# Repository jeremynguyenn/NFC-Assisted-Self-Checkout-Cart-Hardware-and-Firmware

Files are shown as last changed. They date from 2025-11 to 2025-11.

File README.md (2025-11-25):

# Self-Checkout-Shopping-Cart
<p align="middle">
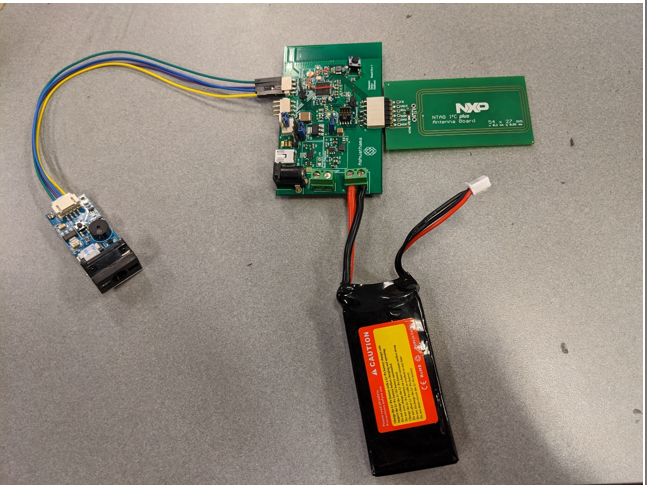
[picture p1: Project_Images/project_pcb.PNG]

</p>

This project was completed in the course Low Power Embedded Design Techniques at University of Colorado, Boulder under the guidance of Prof. Timothy Scherr and Prof. Randall Spalding during September 2019 - December 2019.  

## Hardware Components:
- Blue Gecko EFR32BG13 ([datasheet](https://www.silabs.com/documents/public/data-sheets/efr32bg13-datasheet.pdf))
- NXP NTAG NFC Module ([datasheet](https://www.nxp.com/docs/en/data-sheet/NT3H2111_2211.pdf))
- Barcode Scanner ([datasheet](https://www.waveshare.com/w/upload/3/3c/Barcode_Scanner_Module_User_Manual_EN.pdf))
- Lipo Lithium ion battery ([datasheet](https://cdn.sparkfun.com/datasheets/Prototyping/Lithium%20Ion%20Battery%20MSDS.pdf))
- Buck Converter - TPS560430XFDBVR ([datasheet](http://www.ti.com/general/docs/suppproductinfo.tsp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))
- LDO - LM117 ([datasheet](http://www.ti.com/lit/ds/symlink/lm1117.pdf))
- Battery Charging Management IC - MCP73213 ([datasheet](http://ww1.microchip.com/downloads/en/devicedoc/20002190c.pdf))
- Antenna
- Resistors
- Capacitors
- Inductors
- Adapter Jack
- Micro usb connector
- Debbugger

## Software Components:
- Simplicity Studio
- Android Application

## Features:
- The device connects to an Android app via Bluetooth, with NFC used to perform fast and secure pairing/authentication.

- A barcode module scans QR codes and barcodes to retrieve product details such as name and price through the Low Energy UART peripheral on the EFR32BG13.

- The scanned product information is transmitted to the Android application over BLE using the onboard antenna.

- The Android app displays the list of scanned items along with the total cost in the cart.

- The barcode scanner operates at 5V, while the NFC module requires 3.3V, provided through a buck converter and an LDO regulator respectively.

- The device is powered by a rechargeable battery, supported by an onboard battery-management circuit. A 12V adapter supplies stable power for charging the 7.4V battery.

- A debugger interface is included for flashing firmware and accessing debug print statements (VCOMM).

- Multiple test points and isolation points are placed on the PCB to assist during debugging.

- The board can also receive power from alternative sources through USB.

## Block Diagram:

### Hardware Block Diagram

<p align="middle">
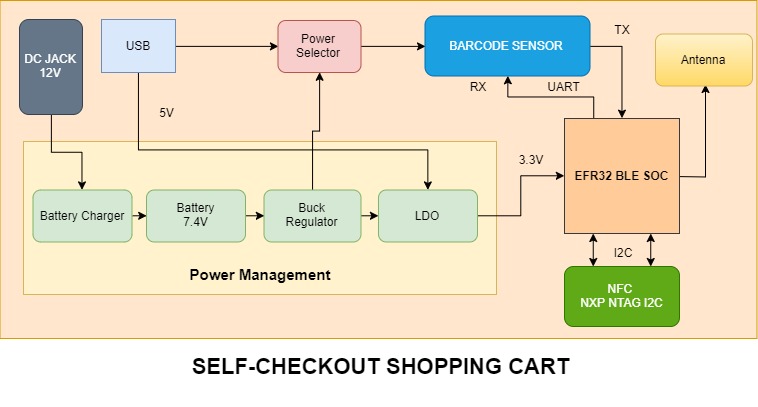
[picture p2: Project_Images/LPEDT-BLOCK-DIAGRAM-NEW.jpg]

</p>

### Software Block Diagram

<p align="middle">
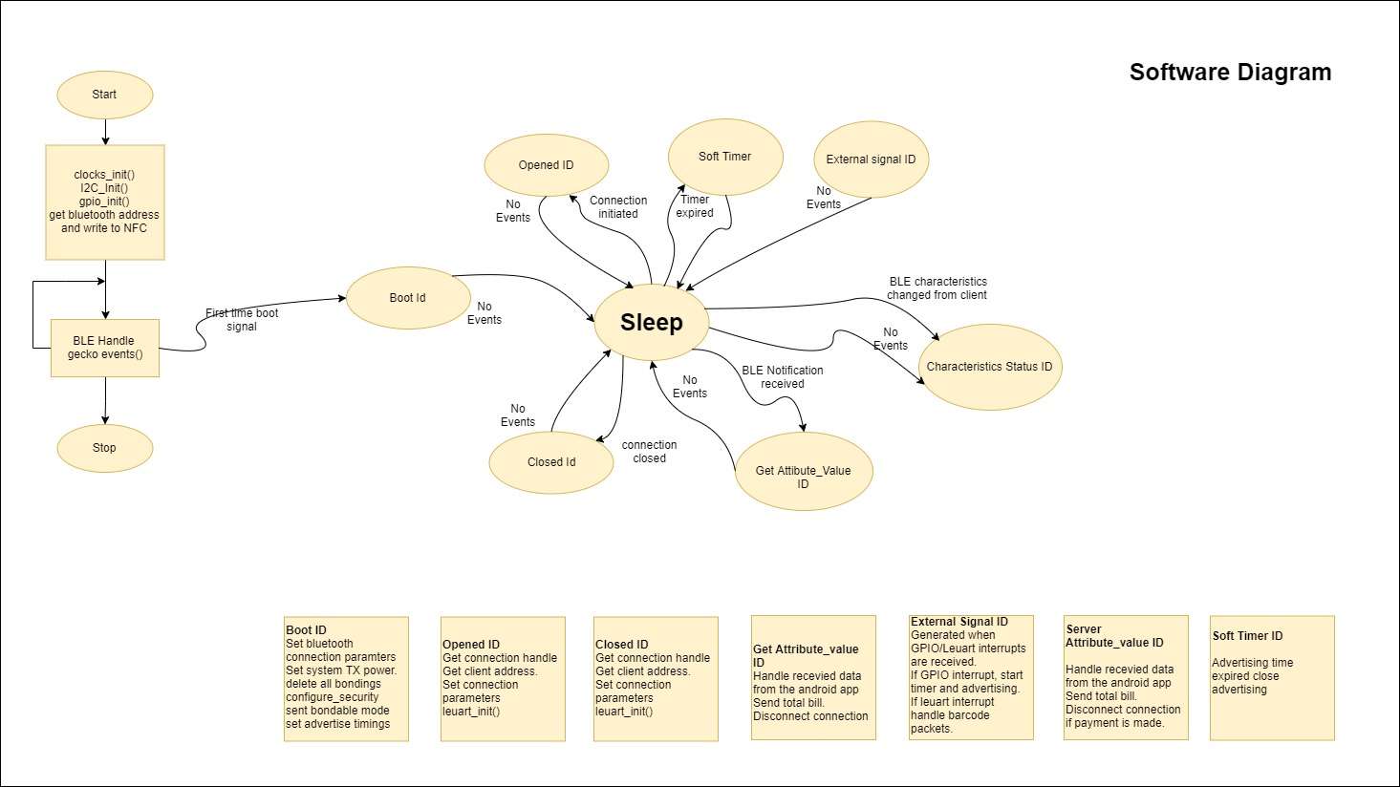
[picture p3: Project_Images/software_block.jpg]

</p>

## Overview:
The “Self-Checkout Shopping Cart” is an innovative consumer purchasing product that is designed to help shoppers fast-track their shopping experience! The shopping cart has an inbuilt barcode scanner which can be used to scan the items to be purchased. The device communicates with the phone over the Bluetooth and bill is generated based on the items. Android app can be used for payment and faster checkout. With the advent of energy efficient devices and low power nodes, it has become imperative to design boards that consume low power which can last longer. To that end, we are designing nodes in order to consume minimal energy and address the issues mentioned below.

PROJECT SOLVES THE FOLLOWING PROBLEMS
1.	Customers usually get annoyed because of the long queues in the billing section of the huge shopping markets. 
2.	In addition to that keeping track of all the bills and budget is a very burdensome task.
3.	Usage of lot of manpower in large supermarkets which can be expensive.
4.	Stock management in supermarkets.
All these problems could be addressed by our “Self-Checkout Shopping Cart”.

SOLUTIONS
1.	Fast self-checkout saves time of customers and helps them buy items according to their budget.
2.	Electronic bill is generated and saved in the cloud which makes it easy to keep track of all the bills and saves paper.
3.	By letting customers handle their own scanning and bagging, workers can spend their time helping customers find what they need. 
4.	Better shopping experience for the customers and an innovative way for the sellers to attract customers.

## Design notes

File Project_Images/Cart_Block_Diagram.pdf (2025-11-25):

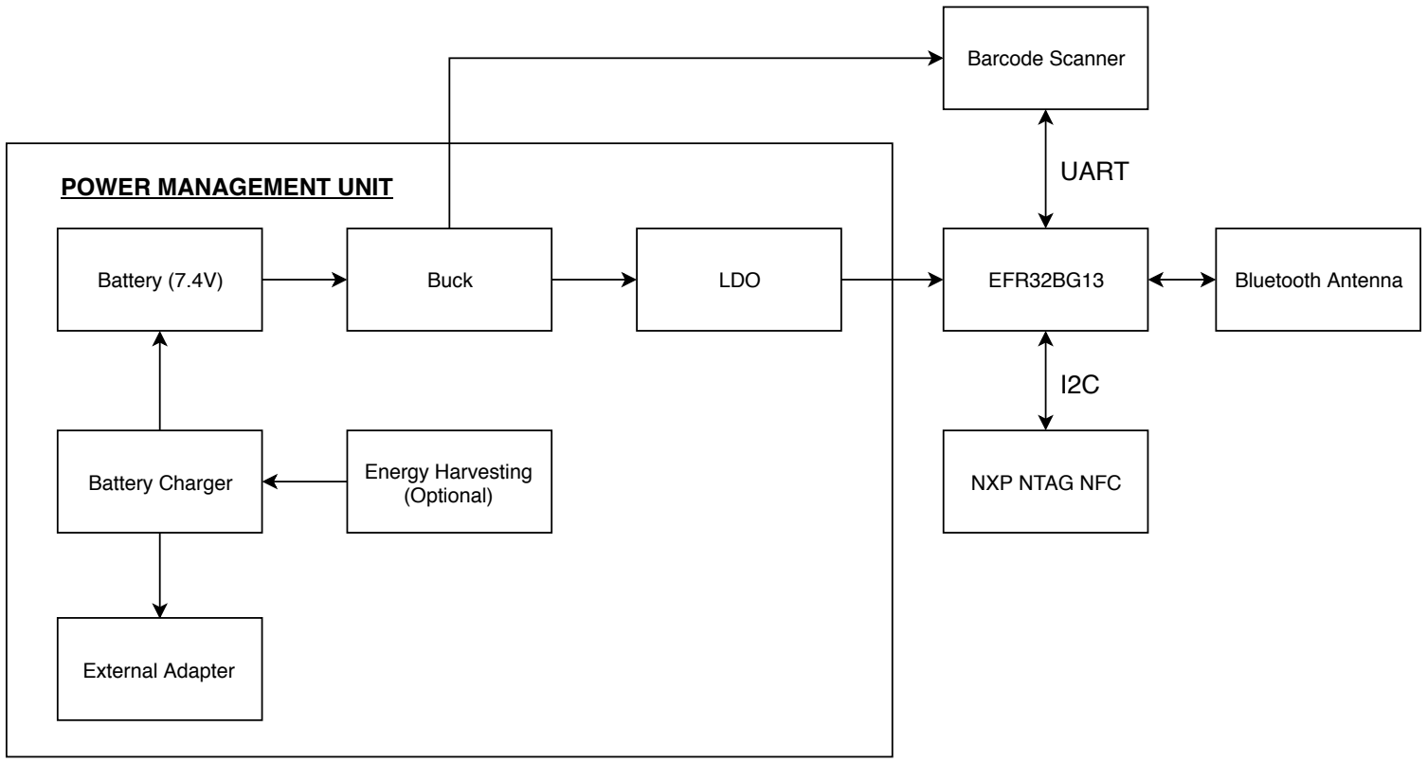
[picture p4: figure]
Battery (7.4V); Battery Charger; External Adapter; Energy Harvesting (Optional); Buck; LDO; EFR32BG13; Bluetooth Antenna; Barcode Scanner; NXP NTAG NFC; UART POWER MANAGEMENT UNIT

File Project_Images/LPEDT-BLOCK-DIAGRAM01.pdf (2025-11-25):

# Amazon Web Services

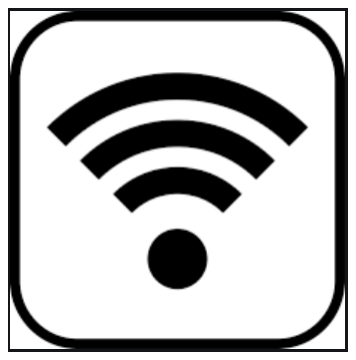
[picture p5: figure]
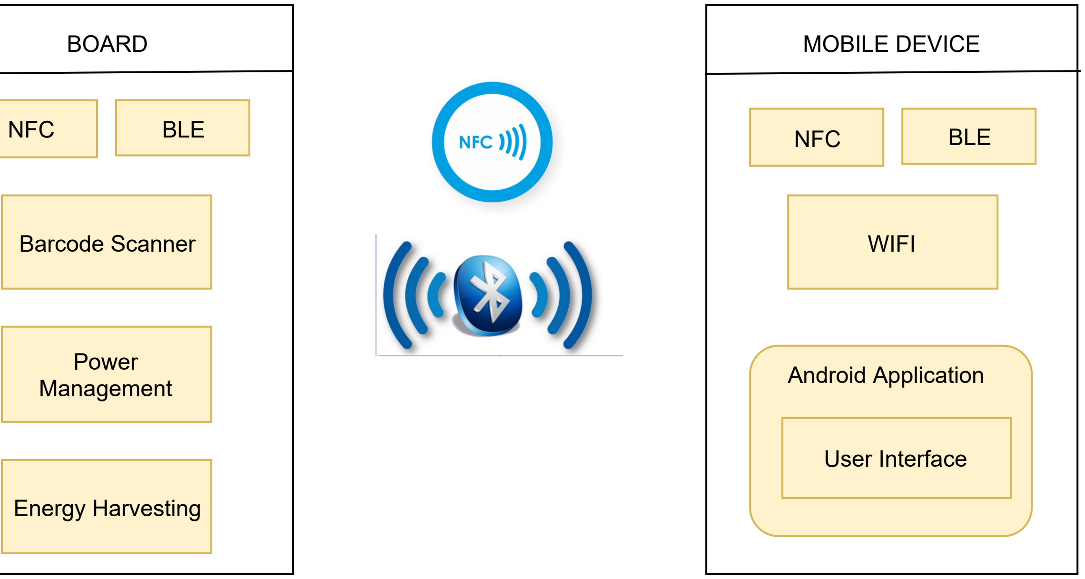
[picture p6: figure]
BOARD; MOBILE DEVICE; NFC; Power Management; BLE; Barcode Scanner; Energy Harvesting; WIFI; Android Application; User Interface
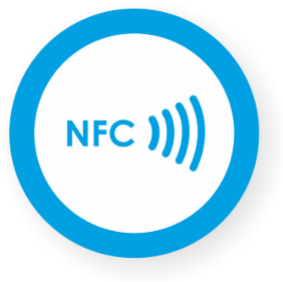
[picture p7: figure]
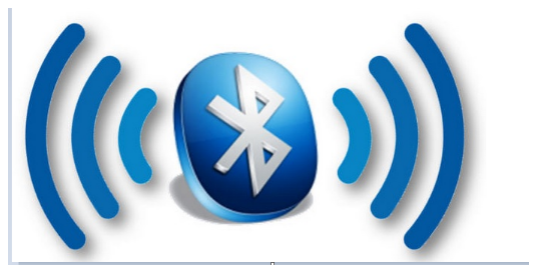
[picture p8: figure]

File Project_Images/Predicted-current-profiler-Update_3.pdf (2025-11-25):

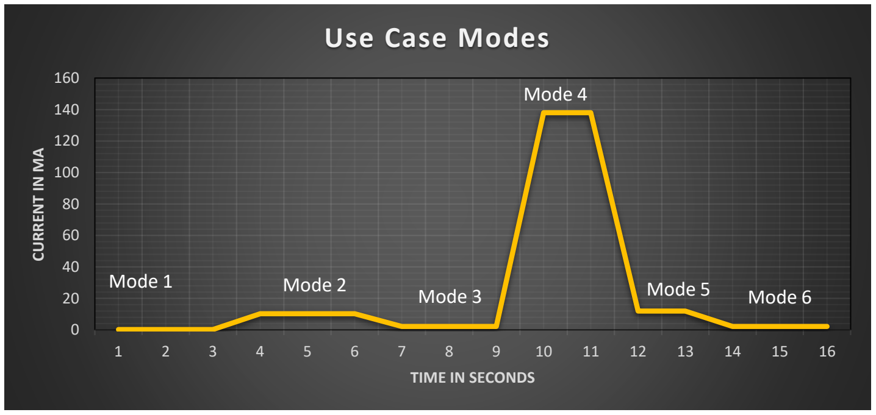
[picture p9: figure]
CURRENT IN MA; TIME IN SECONDS; Use Case Modes; Mode 2; Mode 3; Mode 4; Mode 5; Mode 6; Mode 1

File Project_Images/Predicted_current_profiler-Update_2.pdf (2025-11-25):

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
## CURRENT IN MA

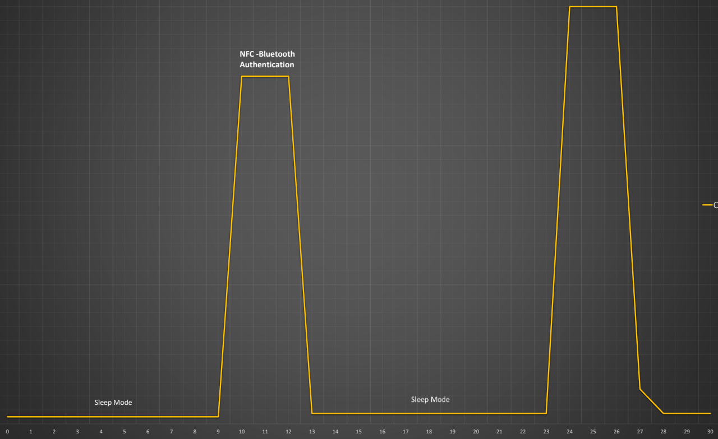
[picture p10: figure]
Sleep Mode; NFC -Bluetooth Authentication

## TIME IN SECS

# Current Profile

# Current

## Successful read

| of sensor

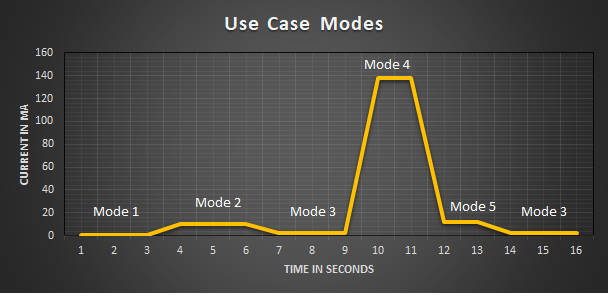
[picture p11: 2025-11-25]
Project_Images/Predicted-current-profiler-Update_3.png

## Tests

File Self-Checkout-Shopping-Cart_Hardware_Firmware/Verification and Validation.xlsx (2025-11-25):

Serial Number | To be Verified | Definition of Passing | Date Test performed | Tested By | Measured Result | Passed? | Links of Images
1 | Check Connections and tracks | Check Continuity of each and every component | 2019-12-02 | Satya | No Discontinuity in any of the tracks | Yes | NA
2 | VCC and Gnd Short circuit | Check for shorts between VCC and GND | 2019-12-02 | Siddhant | No Shorts Between any Power anf GND | Yes | Continuity (https://drive.google.com/open?id=1O2ZVBv9qdy_jvbxbr6DZ3zcfUiEWdlNz)
 | Verifying Battery Input | Check if the Input Voltage is 7.4V | 2019-12-03 |  | Battery Voltage is 7.43V | Yes | Battery Input (https://drive.google.com/open?id=1NyUSMo2W6rnfJJjrChDkwleyFqHzYLkF)
3 | Battery Charging Voltage | Battery charging Voltage should be 8.4V on the connector | 2019-12-03 | Satya | Voltage at Battery Charging Connector is 8.4V | Yes | Battery Charging Voltage (https://drive.google.com/open?id=1OhkqPiOdGKYDeqR6RGebfSnG9Q_gUu2w)
4 | Battery Charging Current | Batter Charging Current should be about 500mA. | 2019-12-03 | Deepesh | Charging Current is about 450mA | Yes | Battery Charging Current (https://drive.google.com/open?id=158kLPGdvDQi1r5bVehvXBsjNyWMkr5Fg)
5 | Buck output Voltage | Buck Output Voltage should be 5V. | 2019-12-03 | Siddhant | Bulk gives 5.025V | Yes | Bulk_Output (https://drive.google.com/open?id=1NtVL5tMdwdIwY26sPy8bp_3PnxwdSYOO)
6 | LDO Output Voltage | LDO Output Voltage should be 3.3V. | 2019-12-03 | Satya | LDO outputs 3.305V | Yes | LDO Output (https://drive.google.com/open?id=1NrpSuceroyJT_VAR9yOWsA_ZSP_1NTEZ)
7 | USB as a Power Supply | Check if Power is delivered on the board to all the components when USB is connected as a source | 2019-12-04 | Deepesh | USB solely powers the Microcontroller, Barode Sensor and NFC | Yes | USB - 5V (https://drive.google.com/open?id=1O46gDnkxgU3gTwBEHZiq3hYbTYlVfkuW) | USB-3V3 (https://drive.google.com/open?id=1O5g_qWqElqR41503nfjX7YFcOhDIGoO6) | USB-LED (https://drive.google.com/open?id=19fPYH5n-wjcmiYV3CqfDkF2il2hSQv3Q)
8 | Check RESET pin Voltage | Reset Pin active Low on Button Press | 2019-12-05 | Satya | Reset pin goes to 0V on resetting Device | Yes | Reset Voltage (https://drive.google.com/open?id=1OFmjtq2S1ZPLpj3BLKayL3nHBryix8i3)
9 | Debugging Cabability | Verify Board's Debugging Capability | 2019-12-05 | Siddhant | Able to burn code using Mini Debugger | Yes | Demo (https://drive.google.com/open?id=1PHqSrd3S05qmIQ_HfaXPMp07Jxs_gFq5)
10 | MCU Test | Test MCU and development environment using simple LED binking program. | 2019-12-05 | Deepesh | Flashed the Simple LED Code and verified | Yes | LED (https://drive.google.com/open?id=1O3ZHA3r2c-B-a-t8yszE2J_bUqXaMPfR)
11 | Debug Prints | Serial Console Capability for Debugging | 2019-12-05 | Siddhant,Satya | Able to perform printf for debugging | Yes | Terminal (https://drive.google.com/open?id=1LyBNWoAG9jryeNOZ93y6Z8e3sn7lz2g-)
12 | Reset Pin Functionality | The Microcontroller should reset itself on pressing the reset button | 2019-12-05 | Satya, Deepesh | Microcontroller resets itself on pressing the reset button | Yes | NA
13 | Communication bus (Signal quality) -I2C | Tap the bus on logic analyzer and verify using protocol analyzer feature. Additional verification using oscilloscope | 2019-12-06 | Satya | Tapped the SCL SDA pins for I2C transaction to verify data transaction | Yes | Logic Analyzer I2C (https://drive.google.com/open?id=1d48Z2fxQN9PpThr4iGMZYQDhR67RP0bd)
14 | Communication bus (Signal quality) -UART | Tap the bus on logic analyzer and verify using protocol analyzer feature. Additional verification using oscilloscope | 2019-12-06 | Siddhant | Tapped TX and RX pins of LEUART to verify Data transaction | Yes | Logic Analyzer UART (https://drive.google.com/open?id=1XVNRgCz_nywQd0K6H3fej32WLSoD1NMq)
15 | UART - Code | Receiving Interrupts on sending a query command for baud rate to the Barcode Scanner | 2019-12-06 | Siddant | UART Interrupts Received on Receive Data. | Yes | UART Code (https://drive.google.com/open?id=1XMtoKkRi8K-EyoNsqtnSocIvW1SvRzNS)
16 | I2C - Code | Read and verify I2C slave address 0xAA. | 2019-12-07 | Satya | I2C transaction Data Verified | Yes | I2C Code (https://drive.google.com/open?id=1XMtoKkRi8K-EyoNsqtnSocIvW1SvRzNS)
17 | GPIO Interrupt | GPIO interrupt received on Field Detect Pin of NFC | 2019-12-10 | Deepesh | On Near-Field Communication Field Detect GPIO Interrupt Occurs | Yes | FD Pin (https://drive.google.com/open?id=1F3u6DmxBmCrzaCM-5mQ-_0tPvc3cTWqC)
18 | Sensor communication | Test proper response is received from the sensor based on the query sent. | 2019-12-06 | Siddhant | Barcode Scanned decoded properly | Yes | Barcode_Data (https://drive.google.com/open?id=1LyBNWoAG9jryeNOZ93y6Z8e3sn7lz2g-)
19 | BLE Advertising | Verify the advertising period as programmed | 2019-12-08 | Satya | Programmed the Code for basic Advertising | Yes | Advertising (https://drive.google.com/open?id=112zhEai5SMZSrbDWJV4xIkbNFkSA3ldP)
20 | BLE Connection | Verify connection of our board and Mobile phone | 2019-12-08 | Deepesh | Andriod App Connected to BlueGecko(address hardcoded) | Yes | Connection (https://drive.google.com/open?id=1Hvsaoi1MEhIo_fBbsnKQTj7bhecBUXqn)
21 | BLE Packets | Test BLE packets being sent and received as expected to the android app | 2019-12-09 | Siddhant, Deepesh | The Android App receives the data about the item scanned | Yes | Demo (https://drive.google.com/open?id=1PHqSrd3S05qmIQ_HfaXPMp07Jxs_gFq5)
22 | NFC Interface | Send NFC packets from Mobile App and verify the data stored in the NFC | 2019-12-10 | Satya | Tag data read successfully and used to connect Blue Gecko using bluetooth | Yes | Demo (https://drive.google.com/open?id=1PHqSrd3S05qmIQ_HfaXPMp07Jxs_gFq5)
23 | Energy Modes | Verifying different energy modes and power consumption using Energy Monitor on Simplicity Studio | 2019-12-13 | Deepesh,Siddhant, Satya | The processor switches through different modes EM2, EM1,EM0 | Yes | Energy Mode (https://drive.google.com/open?id=1A18SZFEd_o9Ry1-VOw-UFNDdMu3-w5bh)
24 | BLE Connection using NFC | Verify successful bluetooth connnection of mobile and board using NFC | 2019-12-12 | Satya, Deepesh | The Bluetooth connection is performed using NFC | Yes | Demo (https://drive.google.com/open?id=1PHqSrd3S05qmIQ_HfaXPMp07Jxs_gFq5)
25 | F Antenna range | Test maximum inverted F Antenna range by checking the connection range | 2019-12-14 | Siddhant, Satya | The F antenna worked for more than 20m. Could work further | Yes | NA

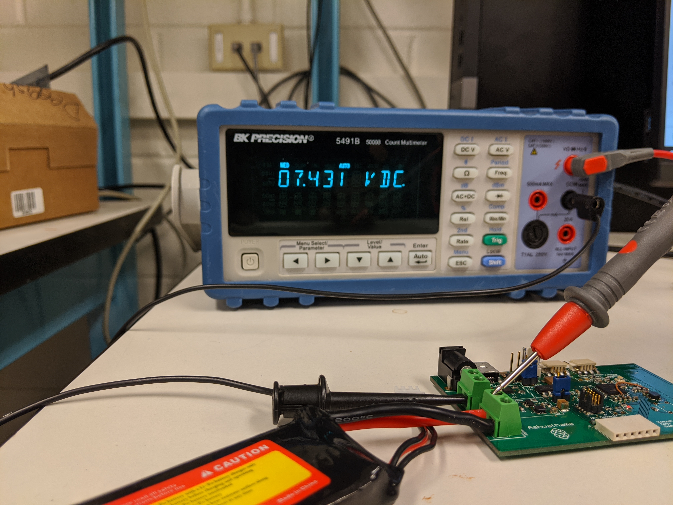
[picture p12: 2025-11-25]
Project_Images/LowPower_Verification/Power_Supply/Battery7V4.jpg

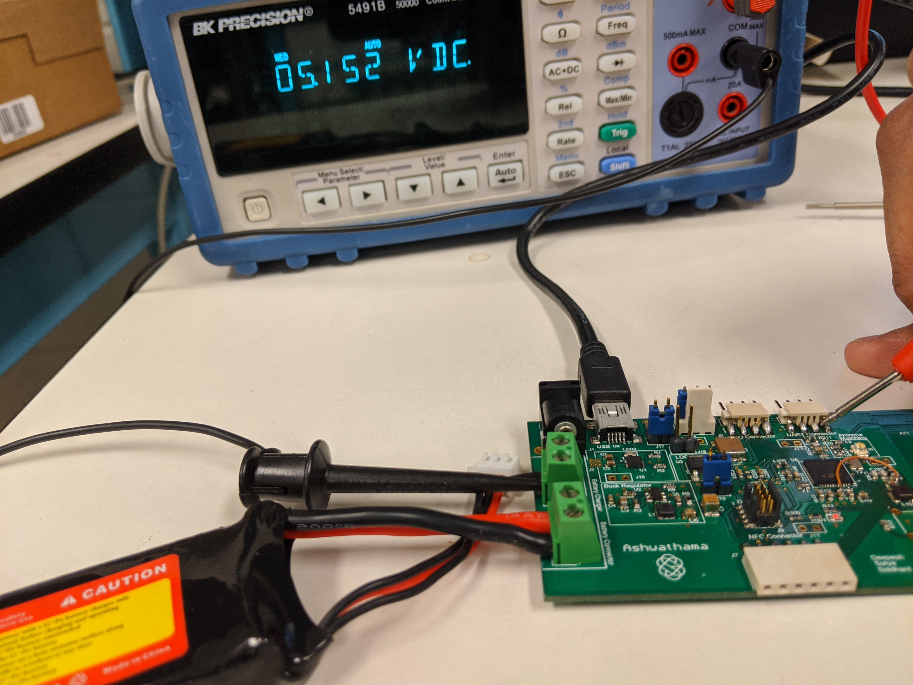
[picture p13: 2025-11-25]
Project_Images/LowPower_Verification/Power_Supply/USB5V.jpg

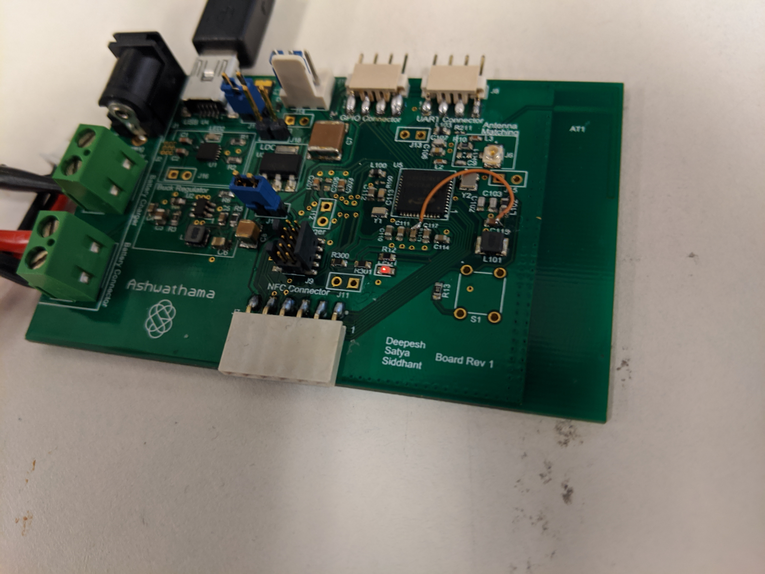
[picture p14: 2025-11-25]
Project_Images/LowPower_Verification/Power_Supply/USB_MicroController.jpg

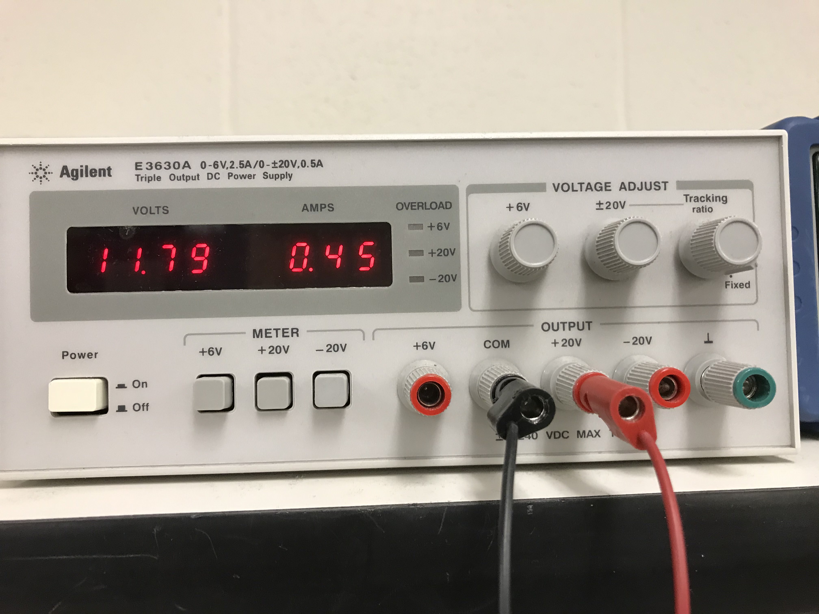
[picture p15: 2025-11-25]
Project_Images/LowPower_Verification/Power_Supply/BatteryCharging.jpg

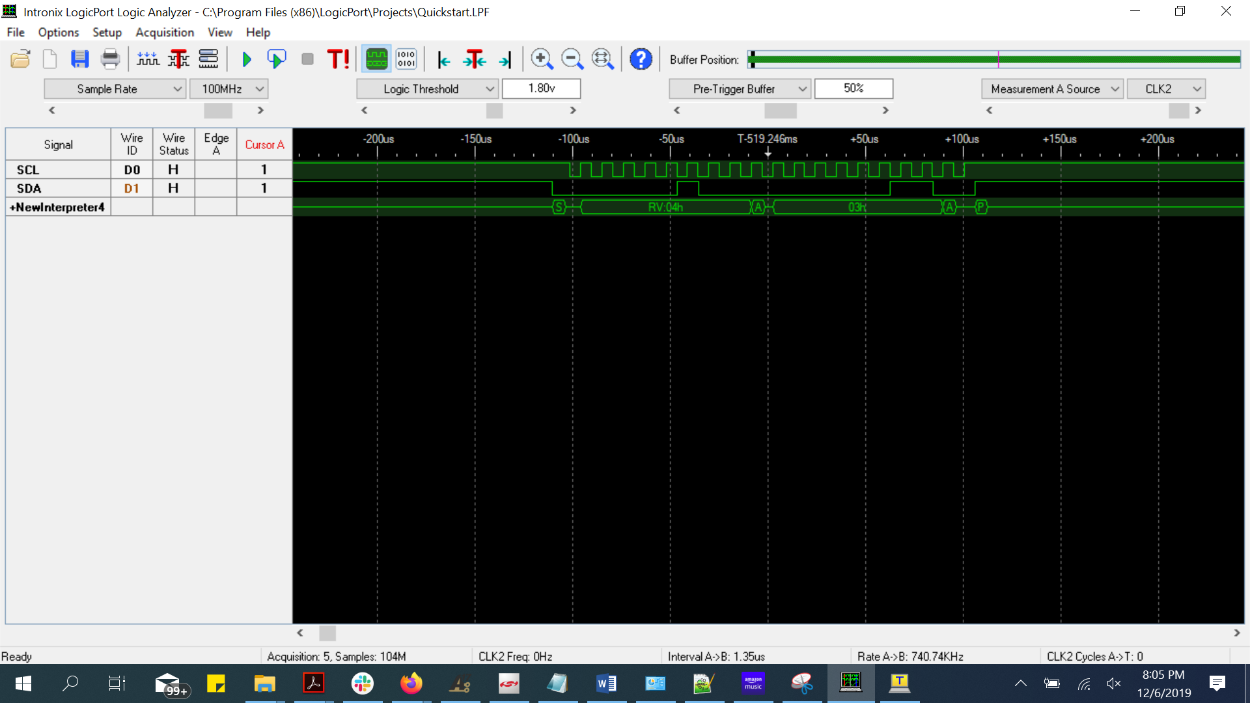
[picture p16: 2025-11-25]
Project_Images/LowPower_Verification/Peripherals/I2c_read.png

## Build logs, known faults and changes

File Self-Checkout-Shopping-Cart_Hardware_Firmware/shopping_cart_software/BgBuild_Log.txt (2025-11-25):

// Copyright 2019 Silicon Laboratories, Inc.
//
//

Executing: bgbuild.exe (C:\SiliconLabs\SimplicityStudio\v4\developer\sdks\gecko_sdk_suite\v2.6\protocol\bluetooth\bin\bgbuild.exe)
Standard output
ALL OK

Error/Warning output
WARNING: 2a00 length attribute is 13 but actual value length is 10. 13 will be used.

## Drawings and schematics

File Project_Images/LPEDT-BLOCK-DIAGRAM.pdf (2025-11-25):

SHOPPING CART | WHEELS

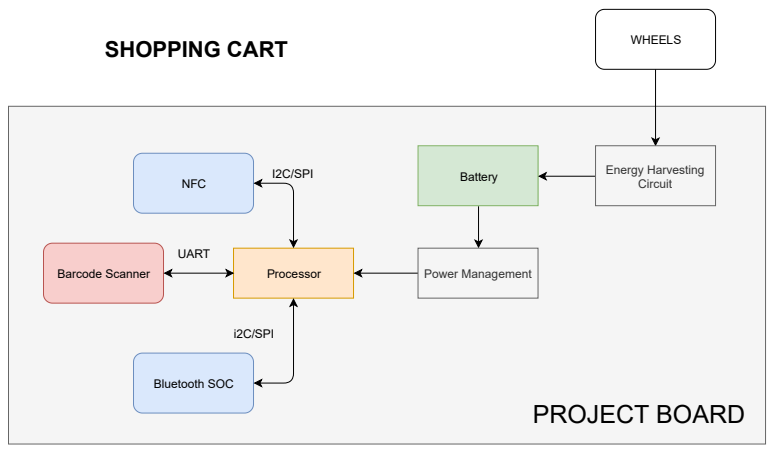
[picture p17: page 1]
Processor; NFC; Bluetooth SOC; Barcode Scanner; UART; I2C/SPI; i2C/SPI; Battery; PROJECT BOARD; Energy Harvesting Circuit; Power Management

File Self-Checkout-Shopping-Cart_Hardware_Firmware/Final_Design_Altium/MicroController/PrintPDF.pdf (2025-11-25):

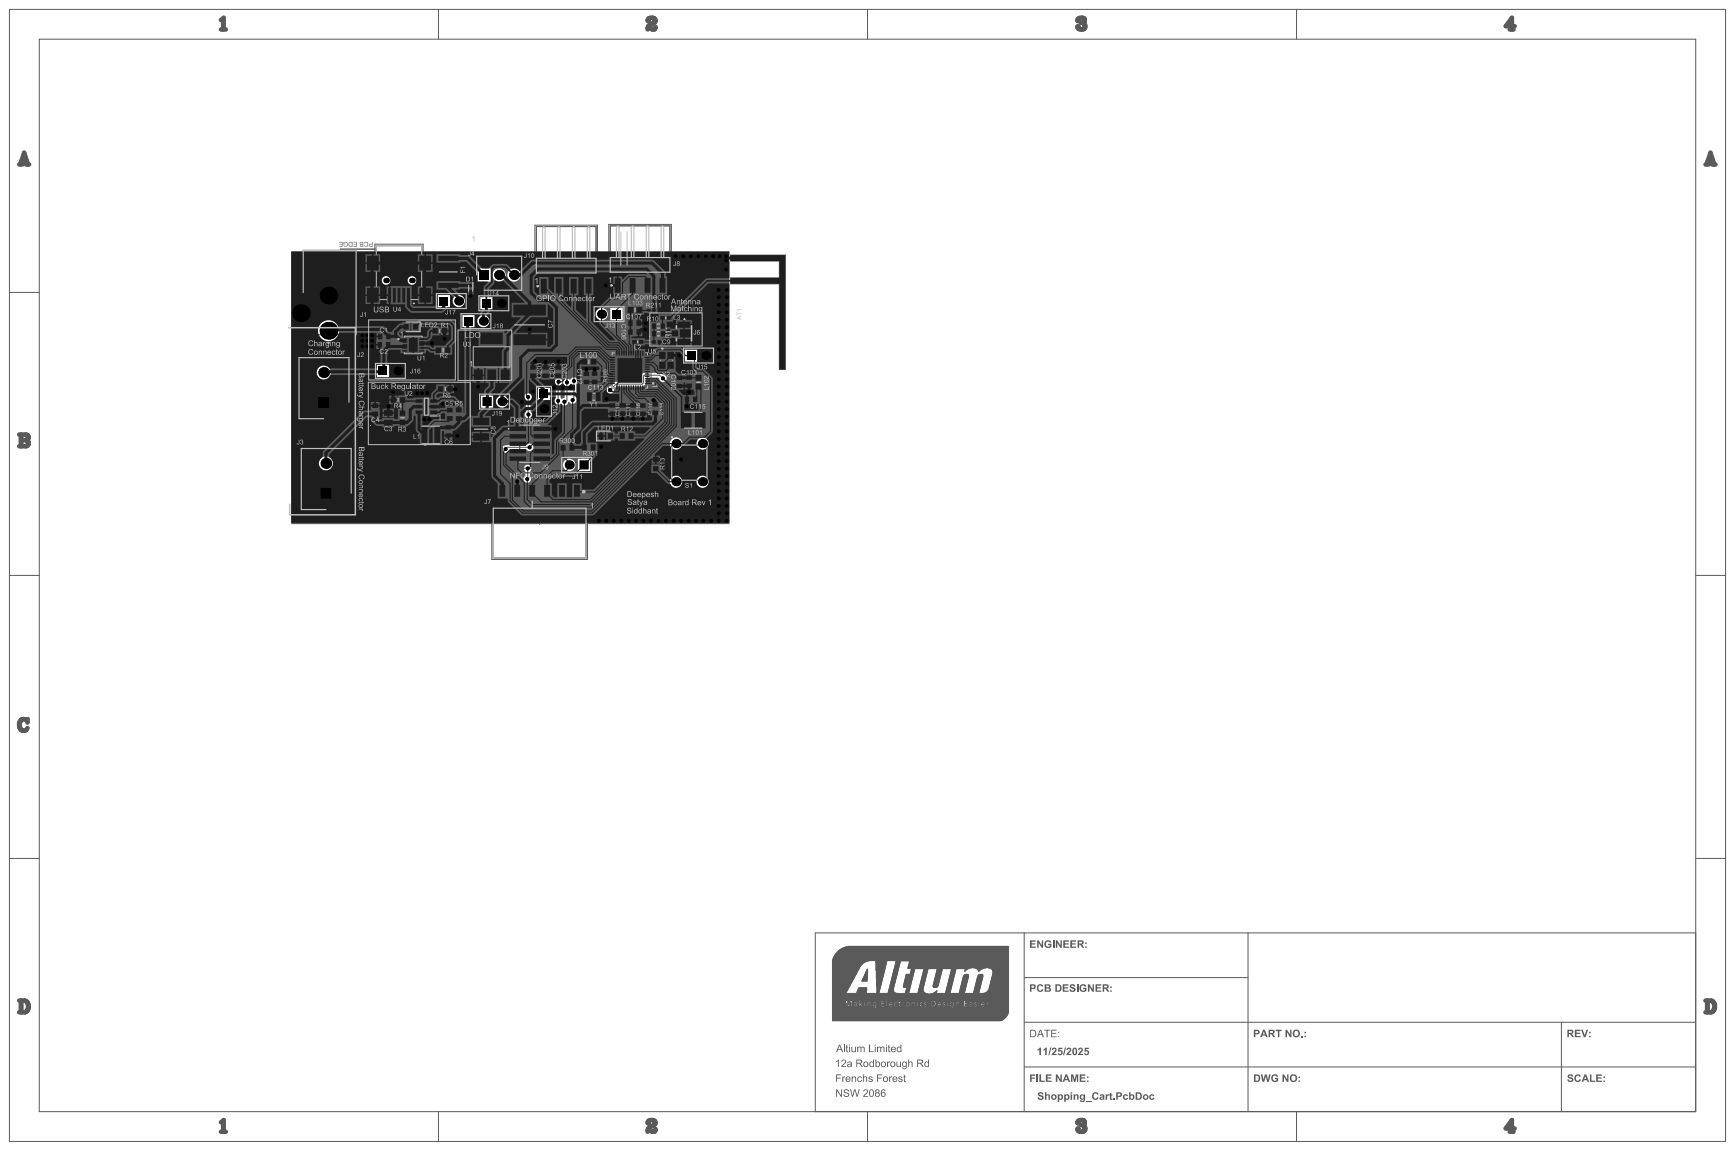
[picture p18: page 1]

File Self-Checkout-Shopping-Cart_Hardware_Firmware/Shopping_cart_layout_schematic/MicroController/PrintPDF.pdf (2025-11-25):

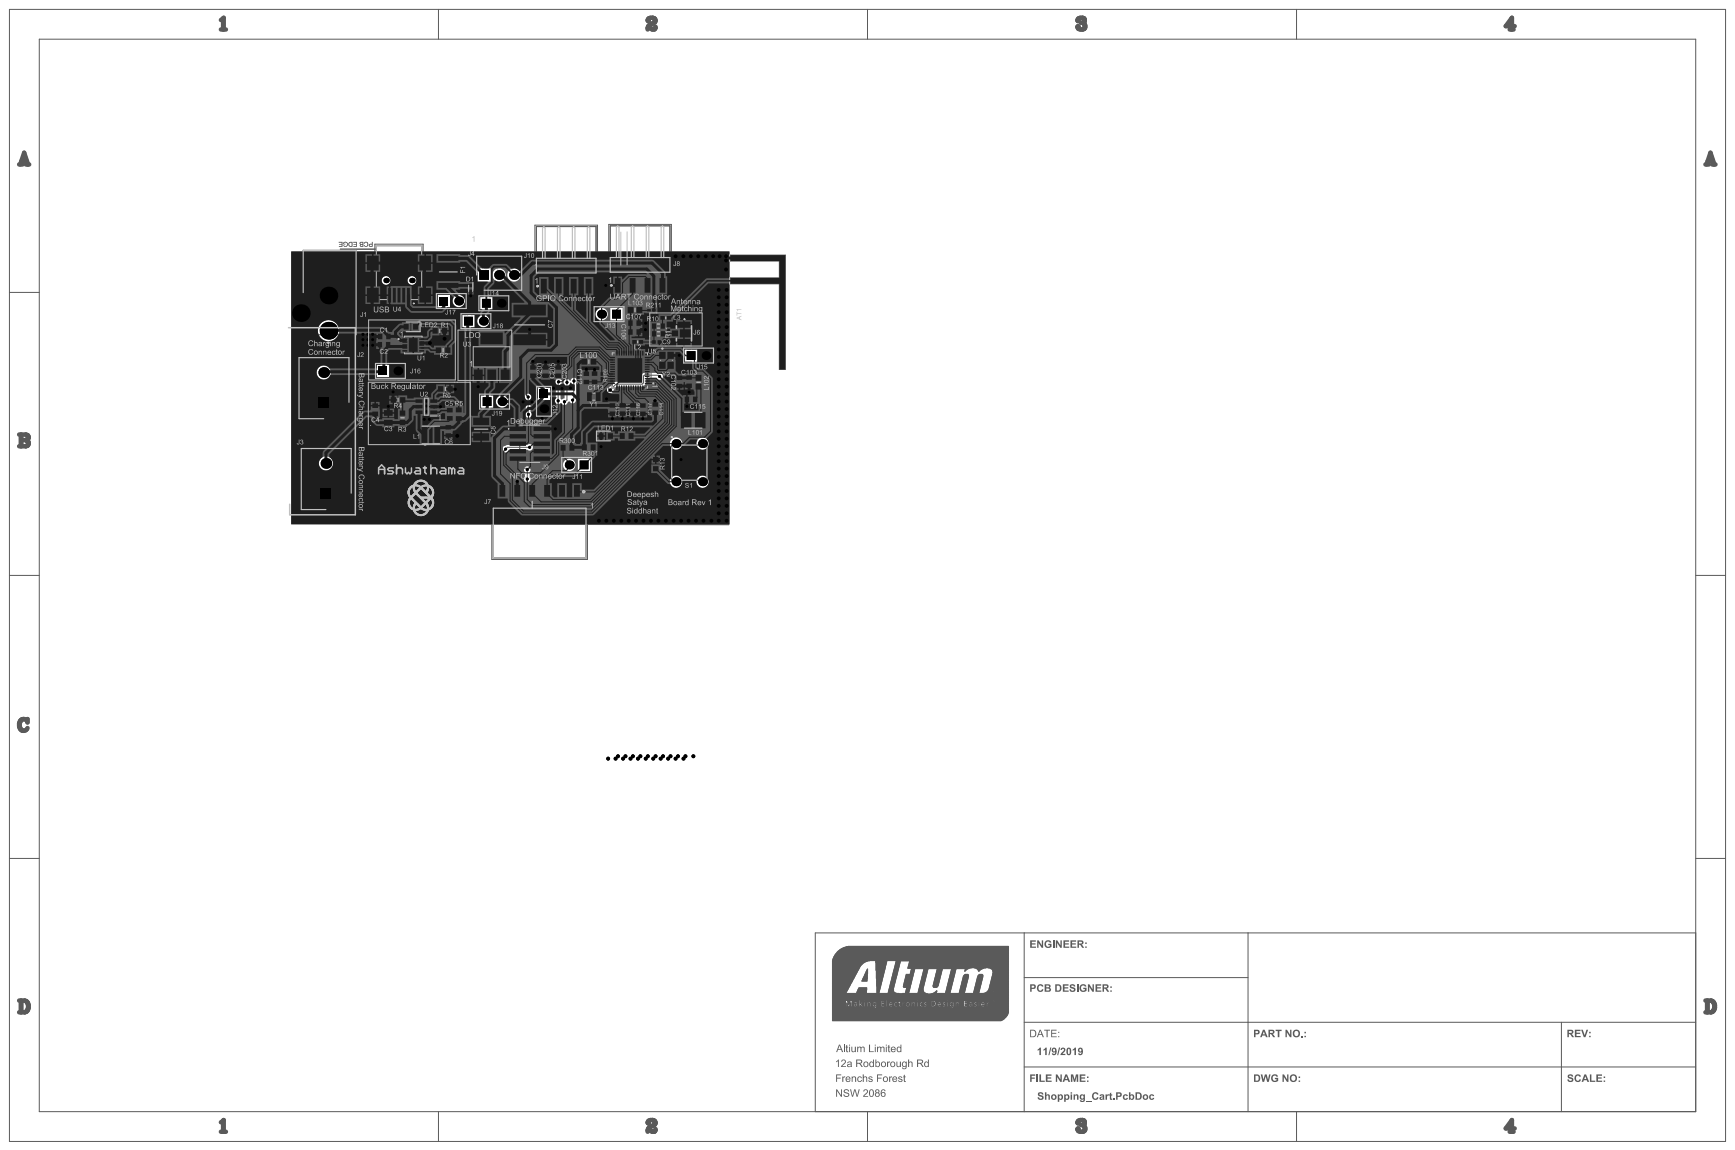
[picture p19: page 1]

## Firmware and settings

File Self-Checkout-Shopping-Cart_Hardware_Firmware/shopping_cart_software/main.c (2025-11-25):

/***************************************************************************//**
 * @file
 * @brief Silicon Labs Empty Example Project
 *
 * This example demonstrates the bare minimum needed for a Blue Gecko C application
 * that allows Over-the-Air Device Firmware Upgrading (OTA DFU). The application
 * starts advertising after boot and restarts advertising after a connection is closed.
 *******************************************************************************
 * # License
 * <b>Copyright 2018 Silicon Laboratories Inc. www.silabs.com</b>
 *******************************************************************************
 *
 * The licensor of this software is Silicon Laboratories Inc. Your use of this
 * software is governed by the terms of Silicon Labs Master Software License
 * Agreement (MSLA) available at
 * www.silabs.com/about-us/legal/master-software-license-agreement. This
 * software is distributed to you in Source Code format and is governed by the
 * sections of the MSLA applicable to Source Code.
 *
 ******************************************************************************/


/* Board headers */
#include "init_mcu.h"
#include "init_board.h"
#include "init_app.h"
#include "ble-configuration.h"
#include "board_features.h"

/* Bluetooth stack headers */
#include "bg_types.h"
#include "native_gecko.h"
#include "gatt_db.h"

/* Libraries containing default Gecko configuration values */
#include "em_emu.h"
#include "em_cmu.h"

/* Device initialization header */
#include "hal-config.h"

#if defined(HAL_CONFIG)
#include "bsphalconfig.h"
#else
#include "bspconfig.h"
#endif

/* Application header */
#include "app.h"
#include "retargetserial.h"
#include "em_core.h"
#include <stdio.h>
#include <stdlib.h>
#include "infrastructure.h"

//Custom header files in INC directory
#include "inc/leuart.h"
#include "inc/connection_param.h"
#include "inc/external_events.h"
#include "inc/barcode.h"
#include "inc/i2c.h"
#include "inc/gpio.h"


/* Global Variables */
#define TIMER_CLK_FREQ 							((uint32)32768)				/* Timer Clock Frequency */
#define TIMER_S_TO_TICKS(s)						(TIMER_CLK_FREQ * s)		/* Convert seconds to timer ticks */
#define SOFT_TIMER_LEUART_INTERRUPT				(55)
#define SOFT_TIMER_NFC_INTERRUPT				(56)
#define CART_DEBUG_PRINTS						(1)							/* Comment this line to remove debug prints */*/
#define EXTRA_PAYLOAD_SIZE						(1 + 1 + 3 + 1 + 1)				/* 1 byte for "," , 1 byte for "$", 3 bytes for cost, 1 byte for "\n" , 1 byte to accomodate NULL character*/
#define MAX_BLUETOOTH_SIZE_SEND					(50)						/* This is the maximum bluetooth data size that can be sent in one go */


#ifdef CART_DEBUG_PRINTS
	#define printf(fmt, args...) printf(fmt, ## args)
#else
	#define printf(fmt, args...)
#endif


#ifndef MAX_ADVERTISERS
#define MAX_ADVERTISERS 1
#endif

#ifndef MAX_CONNECTIONS
#define MAX_CONNECTIONS 4
#endif


uint8_t bluetooth_stack_heap[DEFAULT_BLUETOOTH_HEAP(MAX_CONNECTIONS)];


/* Bluetooth stack configuration parameters (see "UG136: Silicon Labs Bluetooth C Application Developer's Guide" for details on each parameter) */
static gecko_configuration_t config = {
  .config_flags = 0,                                   /* Check flag options from UG136 */
#if defined(FEATURE_LFXO)
  .sleep.flags = SLEEP_FLAGS_DEEP_SLEEP_ENABLE,        /* Sleep is enabled */
#else
  .sleep.flags = 0,
#endif // LFXO
  .bluetooth.max_connections = MAX_CONNECTIONS,        /* Maximum number of simultaneous connections */
  .bluetooth.max_advertisers = MAX_ADVERTISERS,        /* Maximum number of advertisement sets */
  .bluetooth.heap = bluetooth_stack_heap,              /* Bluetooth stack memory for connection management */
  .bluetooth.heap_size = sizeof(bluetooth_stack_heap), /* Bluetooth stack memory for connection management */
  .bluetooth.sleep_clock_accuracy = 100,               /* Accuracy of the Low Frequency Crystal Oscillator in ppm. *
                                                       * Do not modify if you are using a module                  */
  .gattdb = &bg_gattdb_data,                           /* Pointer to GATT database */
  .ota.flags = 0,                                      /* Check flag options from UG136 */
  .ota.device_name_len = 3,                            /* Length of the device name in OTA DFU mode */
  .ota.device_name_ptr = "OTA",                        /* Device name in OTA DFU mode */
#if (HAL_PA_ENABLE)
  .pa.config_enable = 1,                               /* Set this to be a valid PA config */
#if defined(FEATURE_PA_INPUT_FROM_VBAT)
  .pa.input = GECKO_RADIO_PA_INPUT_VBAT,               /* Configure PA input to VBAT */
#else
  .pa.input = GECKO_RADIO_PA_INPUT_DCDC,               /* Configure PA input to DCDC */
#endif // defined(FEATURE_PA_INPUT_FROM_VBAT)
#endif // (HAL_PA_ENABLE)
  .rf.flags = GECKO_RF_CONFIG_ANTENNA,                 /* Enable antenna configuration. */
  .rf.antenna = GECKO_RF_ANTENNA,                      /* Select antenna path! */
};



/* Global Variables */
static uint8_t boot_to_dfu = 0;					// Flag for indicating DFU Reset must be performed
static uint8_t connection_handle;
int payload_size = 0;							/* Payload_size to be sent to the android application */
int total_cost = 0;								/* Total cost of the shopping list is stored here */


uint8_t write_nfc_row[16] = {0x03, 0x18, 0xD1, 0x01, 0x14, 0x54, 0x02, 0x65, 0x6E, 0x30, 0x30, 0x3A, 0x30, 0x42, 0x3A, 0x35};
uint8_t write_nfc_row_1[16] = {0x37, 0x3A, 0x45, 0x46, 0x3A, 0x32, 0x39, 0x3A, 0x42, 0x31, 0xFE, 0x4F, 0x00, 0x00, 0x00, 0x00};




/* Function Declarations */
static void handle_gecko_event(uint32_t evt_id, struct gecko_cmd_packet *evt);
static void bt_connection_init(void);
static void bt_server_print_address(void);
static void write_ble_address_to_nfc(void);



/**
 * @brief  Main function
 */
int main(void)
{
  /* Initialize device */
  initMcu();

  /* Initialize board */
  initBoard();

  /* Initialize application */
  initApp();

  /* Initializing Bluetooth Stack Configuration */
  gecko_init(&config);

  /* UART Console Setup for Debugging */
  RETARGET_SerialInit();
  RETARGET_SerialCrLf(true);

  printf("Self Checkout Shopping Cart.\n");
  printf("Team Name: Ashwathama.\n");

  //Initializing Structures Circular Buffer and Barcode Packet to value 0
  memset(&leuart_circbuff, 0, sizeof(struct leuart_circbuff));
  memset(&barcode_packet, 0, sizeof(struct barcode_packet));

  /* Initializing GPIO Interrupts for NFC, LEUART and I2C*/
  gpio_init();
  i2c_init();

  //Starting Software Timer for leuart interrupts.
  //gecko_cmd_hardware_set_soft_timer(TIMER_S_TO_TICKS(1), SOFT_TIMER_LEUART_INTERRUPT, 0);


  while (1)
  {
	  struct gecko_cmd_packet *evt = gecko_wait_event();
	  handle_gecko_event(BGLIB_MSG_ID(evt->header), evt);
  }
}



/**
 * @brief This function handles all the gecko events.
 */
static void handle_gecko_event(uint32_t evt_id, struct gecko_cmd_packet *evt)
{
	switch (evt_id) {
	case gecko_evt_dfu_boot_id:
		printf("Event: gecko_evt_dfu_boot_id\n");
		break;


	case gecko_evt_system_boot_id:
		printf("Event: gecko_evt_system_boot_id\n");

		/*Set up Bluetooth connection parameters and start advertising */
		bt_connection_init();

		break;


	/* This event is generated when a connected client has either
	 * 1) changed a Characteristic Client Configuration, meaning that they have enabled
	 * or disabled Notifications or Indications, or
	 * 2) sent a confirmation upon a successful reception of the indication. */
	case gecko_evt_gatt_server_characteristic_status_id:
		printf("Event: gecko_evt_gatt_server_characteristic_status_id\n");
		break;


	case gecko_evt_le_connection_opened_id:

		printf("Event: gecko_evt_le_connection_opened_id\n");
		char client_address_string[6];

		/* Disabling NFC software timer on successful connection */
		gecko_cmd_hardware_set_soft_timer(0, SOFT_TIMER_NFC_INTERRUPT, 0);

		/* Enabling leuart only after successful connection */
		leuart_init();

		/*Configure Connection Parameters*/
		gecko_cmd_le_connection_set_parameters(evt->data.evt_le_connection_opened.connection,
													CON_INTERVAL_MIN,CON_INTERVAL_MAX,CON_LATENCY,CON_TIMEOUT);
		connection_handle = evt->data.evt_le_connection_opened.connection;

		bd_addr client_address = evt->data.evt_le_connection_opened.address;
		sprintf(client_address_string,"X:X:X:X:%x:%x",client_address.addr[1],client_address.addr[0]);
		printf("Client Address: %s \n", client_address_string);

		break;


	case gecko_evt_sm_bonded_id:
		printf("Event: gecko_evt_sm_bonded_id\n");
		break;


	case gecko_evt_sm_bonding_failed_id:
		printf("Event: gecko_evt_sm_bonding_failed_id\n");
		break;


	case gecko_evt_le_connection_closed_id:
		/* Check if need to boot to dfu mode */
		printf("Event: gecko_evt_le_connection_closed_id\n");
		printf("Disconnected\n");
		total_cost = 0;
		gecko_cmd_system_set_tx_power(0);

		if (boot_to_dfu) {
			/* Enter to DFU OTA mode */
			gecko_cmd_system_reset(2);

		} else {

			/* Stop timer in case client disconnected before indications were turned off */
			gecko_cmd_hardware_set_soft_timer(0, 0, 0);

			/* Start NFC GPIO interrupt to reconnect using NFC */
			GPIO_IntConfig(GPIO_NFC_PORT, GPIO_NFC_PIN, GPIO_RISING_EDGE, GPIO_FALLING_EDGE, GPIO_INTERRUPT_ENABLE);

			/* Disable leuart peripheral over here */
			leuart_disable();
		}
		break;


	case gecko_evt_gatt_server_execute_write_completed_id:
		printf("Event: gecko_evt_gatt_server_execute_write_completed_id\n");
		break;


	case gecko_evt_gatt_service_id:
		printf("Event: gecko_evt_gatt_service_id\n");
		break;


	case gecko_evt_gatt_characteristic_value_id:
		printf("Event: gecko_evt_gatt_characteristic_value_id\n");
		break;


	case gecko_evt_hardware_soft_timer_id:
		switch (evt->data.evt_hardware_soft_timer.handle){
		case SOFT_TIMER_LEUART_INTERRUPT:

			printf("SOFT_TIMER_LEUART_INTERRUPT\n");
			if(!leuart_buffer_empty_status())
			{
				CORE_AtomicDisableIrq();
				external_event |= EVENT_LEUART;
				gecko_external_signal(external_event);
				CORE_AtomicEnableIrq();
			}

			break;

		case SOFT_TIMER_NFC_INTERRUPT:

			printf("SOFT_TIMER_NFC_INTERRUPT\n");
			/* Stop advertising and enable interrupts */
			gecko_cmd_le_gap_stop_advertising(0);
			GPIO_IntConfig(GPIO_NFC_PORT, GPIO_NFC_PIN, GPIO_RISING_EDGE, GPIO_FALLING_EDGE, GPIO_INTERRUPT_ENABLE);


		}
		break;


	case gecko_evt_gatt_server_attribute_value_id:
		printf("Event: gecko_evt_gatt_server_attribute_value_id\n");

		char cost_string[4];
		char *ptr = &cost_string[0];
		ptr = itoa(total_cost, cost_string, 10);
		printf("Total cost decimal: %d\n", total_cost);
		printf("Total Cost String: %s\n",cost_string);
		printf("Received response: %c \n", evt->data.evt_gatt_server_attribute_value.value.data[0]);
		if (evt->data.evt_gatt_server_attribute_value.value.len && (evt->data.evt_gatt_server_attribute_value.value.data[0] == 'B'))
		{
			printf("Sending Bill\n");
			printf("Send Result: %x\n",gecko_cmd_gatt_server_send_characteristic_notification(
					(uint8)connection_handle, (uint8)gattdb_product_name, (uint8)4, (const uint8*)ptr)->result);
		}
		else if (evt->data.evt_gatt_server_attribute_value.value.len && (evt->data.evt_gatt_server_attribute_value.value.data[0] == 'P'))
		{
			printf("Total Cost set to 0\n");
			total_cost = 0;
			gecko_cmd_le_connection_close(connection_handle);		//Closing the connection since payment is completed
		}



		break;


	case gecko_evt_gatt_procedure_completed_id:
		printf("GATT Procedure completed\n");
		break;


	case gecko_evt_system_external_signal_id:
		printf("Event: gecko_evt_system_external_signal_id\n");

		if (evt->data.evt_system_external_signal.extsignals & EVENT_LEUART)
		{

			CORE_AtomicDisableIrq();
			external_event &= ~EVENT_LEUART;
			CORE_AtomicEnableIrq();

			printf("External Signal Event for LEUART received.\n");

			//Initial data - Not necessary to initialize
			uint32_t temp_read_index = leuart_circbuff.read_index;

			/* Read data from leuart_circbuff till it is empty */
			while(!leuart_buffer_empty_status())
			{

				//TODO: Add a Software Timer for UART Receiving external event trigger.
				if(leuart_circbuff.buffer[leuart_circbuff.read_index] == BARCODE_PREAMBLE)
				{
					temp_read_index = leuart_circbuff.read_index + 7;							/* 7 as per the packet structure */

					/* Start making packet here */
					total_cost += barcode_packet_create(&barcode_packet, &payload_size);

				}
				else if(leuart_circbuff.buffer[leuart_circbuff.read_index] == BARCODE_POSTAMBLE)
				{
					/* Temporary packet to send data. Maxmum size BLE can transfer at a time is 20 bytes */
					char packet_send[MAX_BLUETOOTH_SIZE_SEND];
					int total_payload_size = payload_size + EXTRA_PAYLOAD_SIZE;

					memset(packet_send, 0, sizeof(packet_send));

					/* Pop the postamble and the \r character*/
					barcode_packet.postamble = leuart_buffer_pop();
					leuart_buffer_pop();														/* To remove the redundant \r received from the barcode*/

					/* Copy the received buffer data into the packet structure and append a null character to the string at the end */
					memcpy(&barcode_packet.payload[0], &leuart_circbuff.buffer[temp_read_index], payload_size);
					barcode_packet.payload[payload_size] = '\0';								/* Adding a NULL character at the end of string*/


					//TODO: Now Start Sending data over bluetooth here.
					snprintf(packet_send, total_payload_size, "%s,$%s\n", barcode_packet.payload, &barcode_packet.cost[0]);
					printf("Packet to be sent over Bluetooth: %s \n", packet_send);

					do
					{
						if (total_payload_size <= MAX_BLUETOOTH_SIZE_SEND)
						{
							printf("Send Result: %x\n",gecko_cmd_gatt_server_send_characteristic_notification(
									connection_handle, gattdb_product_name, total_payload_size, (const uint8 *)&packet_send[0])->result);
						}
						total_payload_size -= MAX_BLUETOOTH_SIZE_SEND;
					}
					while( total_payload_size > 0 /*&& (total_payload_size / MAX_BLUETOOTH_SIZE_SEND)*/);


					/* Free the barcode_packet data structure after sending data */
					free(barcode_packet.payload);

					/* Initializing the barcode_packet data structure to zero */
					memset(&barcode_packet, 0, sizeof(struct barcode_packet));
				}
				else
				{
					leuart_buffer_pop();														/* To pop remaining data*/
				}
			}
		}

		if (evt->data.evt_system_external_signal.extsignals & EVENT_NFC_GPIO)
		{

			CORE_AtomicDisableIrq();
			external_event &= ~EVENT_NFC_GPIO;
			CORE_AtomicEnableIrq();

			printf("External Signal Event for NFC FD pin interrupt received.\n");

			gecko_cmd_le_gap_start_advertising(0, le_gap_general_discoverable, le_gap_connectable_scannable);

			gecko_cmd_hardware_set_soft_timer(TIMER_S_TO_TICKS(15), SOFT_TIMER_NFC_INTERRUPT, 1);

		}

		break;



	/* Events related to OTA upgrading
			   ----------------------------------------------------------------------------- */

	/* Checks if the user-type OTA Control Characteristic was written.
	 * If written, boots the device into Device Firmware Upgrade (DFU) mode. */
	case gecko_evt_gatt_server_user_write_request_id:
		printf("Write request receieved from the mobile app\n");
		if (evt->data.evt_gatt_server_user_write_request.characteristic == gattdb_ota_control) {
			/* Set flag to enter to OTA mode */
			boot_to_dfu = 1;
			/* Send response to Write Request */
			gecko_cmd_gatt_server_send_user_write_response(
					evt->data.evt_gatt_server_user_write_request.connection,
					gattdb_ota_control,
					bg_err_success);

			/* Close connection to enter to DFU OTA mode */
			gecko_cmd_le_connection_close(evt->data.evt_gatt_server_user_write_request.connection);
		}
		break;

	default:
		break;
	}
}



/**
 * @brief This function prints the Server Bluetooth Public address
 * @param void
 * @return void
 */
static void bt_server_print_address(void)
{
	char server_address_string[6];
	struct gecko_msg_system_get_bt_address_rsp_t *bt_addr = gecko_cmd_system_get_bt_address();
	bd_addr *server_address = &bt_addr->address;

	sprintf(server_address_string,"%x:%x:%x:%x:%x:%x", server_address->addr[5],server_address->addr[4]
												,server_address->addr[3],server_address->addr[2],
												server_address->addr[1],server_address->addr[0]);
	printf("Server Address: %s \n", server_address_string);
}


/**
 * @brief This function initializes the bluetooth connection.
 * The function prints the server address, deletes all previous bondings, sets into bonding mode,
 * sets the transmit power to zero, configures and starts advertising.
 * @param void
 * @return void
 */
static void bt_connection_init(void)
{
	//Prints the Server Bluetooth Public address
	bt_server_print_address();

	//Setting Transmit Power
	gecko_cmd_system_set_tx_power(0);

	// Delete all previous bondings
	gecko_cmd_sm_delete_bondings();

	// Configure Security
	gecko_cmd_sm_configure(SECURITY_CONFIGURE_FLAG,sm_io_capability_noinputnooutput);

	//Set into Bondable Mode
	gecko_cmd_sm_set_bondable_mode(1);

	// Configure and start general advertising and enable connections.
	gecko_cmd_le_gap_set_advertise_timing(ADV_HANDLE, ADV_INTERVAL_MIN, ADV_INTERVAL_MAX, ADV_TIMING_DURATION, ADV_MAXEVENTS);

}


static void write_ble_address_to_nfc(void)
{
	struct gecko_msg_system_get_bt_address_rsp_t *add = gecko_cmd_system_get_bt_address();
	char address[40];
	snprintf(address, 40, "%02x:%02x:%02x:%02x:%02x:%02x",
			add->address.addr[5],
			add->address.addr[4],
			add->address.addr[3],
			add->address.addr[2],
			add->address.addr[1],
			add->address.addr[0]
	);

	uint8_t bluegecko_address[17] = {((add->address.addr[5] & (0xF0)) >> 4), (add->address.addr[5] & (0x0F)), 58, ((add->address.addr[4] & (0xF0)) >> 4), (add->address.addr[4] & (0x0F)), 0x3A,
									 ((add->address.addr[3] & (0xF0)) >> 4), (add->address.addr[3] & (0x0F)), 58, ((add->address.addr[2] & (0xF0)) >> 4), (add->address.addr[2] & (0x0F)), 0x3A,
									 ((add->address.addr[1] & (0xF0)) >> 4), (add->address.addr[1] & (0x0F)), 58, ((add->address.addr[0] & (0xF0)) >> 4), (add->address.addr[0] & (0x0F))};
	char bluegecko_char_address[17];
	printf("Blue Gecko Address : ");
	char *bt_ptr = bluegecko_char_address;
	for(int i = 0; i < 17; i++)
	{
		//printf("%x", bluegecko_address[i]);
		bt_ptr = itoa(bluegecko_address[i], bt_ptr, 16);
		bt_ptr++;
	}
	for (int i = 0; i < 17; i++)
	{
		if (i == 2 || i == 5 || i == 8 || i == 11 || i == 14)
		{
			bluegecko_char_address[i] = ':';
		}
	}
	printf("Blue gecko char add :");
	for (int i = 0; i < 17; i++)
	printf("%d\n", bluegecko_char_address[i]);
	for (int i = 9; i < 16; i++)
		write_nfc_row[i] = bluegecko_char_address[i-9];
	for(int i = 0; i < 10; i++)
		write_nfc_row_1[i] = bluegecko_char_address[i + 7];

//	printf("Writw row 1 %s\n", (char *)write_nfc_row);
	printf("Writw row 2 %s\n", write_nfc_row_1);
	i2c_write_poll(0x02, write_nfc_row_1);
	for(int i = 0; i < 1000000; i++);
	i2c_write_poll(0x01, write_nfc_row);
	printf("Address written in NFC Module\n");
}


/** @} (end addtogroup app) */
/** @} (end addtogroup Application) */

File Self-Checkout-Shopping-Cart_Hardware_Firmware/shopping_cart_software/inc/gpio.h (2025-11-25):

/*
 * @file gpio.h
 * @brief Header file for gpio.c
 *
 * @author: Siddhant Jajoo.
 * @date 12/08/2019
 * @copyright Copyright (c) 2019
 *
 */


#ifndef INC_GPIO_H_
#define INC_GPIO_H_


/* Macros */
#define GPIO_NFC_PORT							(gpioPortC)
#define GPIO_NFC_PIN							(9)								/* Pin number 10 */
#define GPIO_RISING_EDGE						(false)
#define GPIO_FALLING_EDGE						(true)
#define GPIO_INTERRUPT_ENABLE					(true)
#define GPIO_NFC_INTERRUPT_FLAG					(0x01 << GPIO_NFC_PIN)			/*FD Pin interrupt*/


/* Function Declarations */
void gpio_init(void);



#endif /* INC_GPIO_H_ */
